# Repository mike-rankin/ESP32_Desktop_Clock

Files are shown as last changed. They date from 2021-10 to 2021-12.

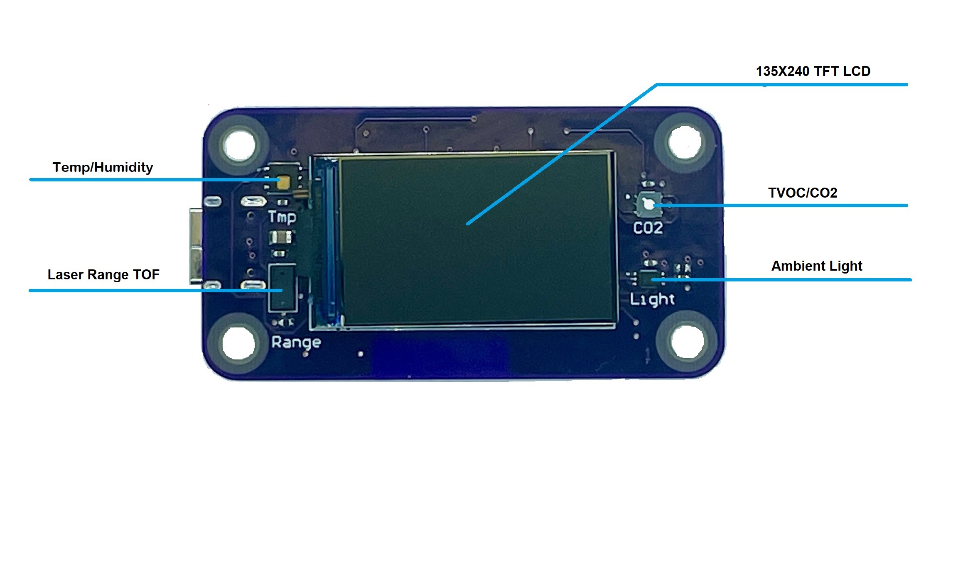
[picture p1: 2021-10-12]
Images/Front_Components.jpg

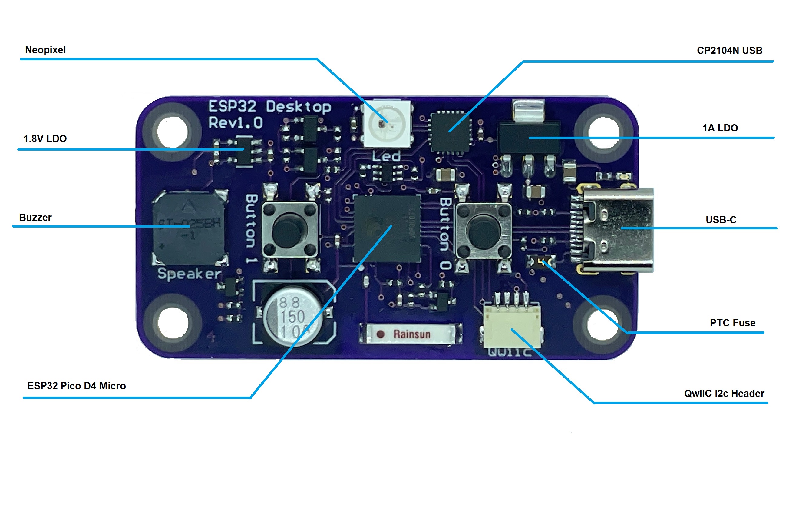
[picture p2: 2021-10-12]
Images/Back_Components.jpg

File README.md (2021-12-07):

# ESP32_Desktop_Clock
ESP32 based Desktop Clock





Front_Components

Back_Components

# Click below for a video of it doing its thing
Video of it doing its thing (https://www.youtube.com/watch?v=Y3FI6KhXrEo)

This ESP32 internet of things desktop clock is a project created for my home. School has started and fall is coming so every morning my kids ask me what they should wear. This clock is normally very, very dim and shows the time, co2 value, room temperature and humidity in a dark orange color. When you move your hand a foot or so in front, the time fades away to a screen showing the days low temperature, high and what the weather conditions will be. Time is updated every few minutes over wifi from an NTP server, local weather data is updated from Openweather with various sensors on the front. 

Hardware on this board:<br/>
-ESP32 Pico D4 processor<br/>
-temperature/humidity sensor (HDC1080DMBT)<br/>
-laser range sensor (VL53L0CXV0DH)<br/>
-CO2/TVOC (SGP-30-2.5K)<br/>
-ambient light sensor (BH1750FVI)<br/>
-135x240 TFT LCD (ER-TFT1.14-1)<br/>
-3.3V LDO (NCP1117LPST33T3G)<br/>
-1.8V LDO (RT9193-18GB)<br/>
-Neopixel LED<br/>
-USB interface (CP2104N)<br/>
-USB-C Connector<br/>
-QwiiC i2c Connector<br/>
-Buzzer<br/>

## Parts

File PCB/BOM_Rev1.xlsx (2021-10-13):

Designator | Quantity | Vendor | PartNumber | Description | Manufacturer | Value
A1 | 1 | LCSC | C99665 | Antenna Chip 2.4Gig | Rainsun | Chip Antenna
BZ1 | 1 | Digi-Key | ST-025BH | BUZZER MAGNETIC 2.7kHz Tone 2-4V SMD | SOBERTON
C1 | 1 | LCSC |  | CAP 1uF 0402 |  | 1uF
C2 | 1 | LCSC |  | CAP 22nF 0402 |  | 22nF
C3, C11 | 2 | LCSC | C83063 | CAP 1uF 16V 0402 | Walsin | 1uF
C4, C10, C14, C18 | 4 | LCSC |  | CAP 0.1uF 0402 |  | 0.1uF
C5 | 1 | LCSC | C147344 | CAP 1.5pF 0402 | Dafron | 1.5pF
C6, C8, C16, C17 | 4 | LCSC | C344190 | CAP 0.1uF 0402 | CCTC | 0.1uF
C7 | 1 | LCSC | C242018 | CAP 150uF, 10V SMT | Suncon | 150uF
C9, C15 | 2 | LCSC | C307520 | CAP 10uF 0805 | Samsung | 10uF
C12, C13 | 2 | LCSC | C162317 | CAP 10uF 16V 0805 | Murata | 10uF
D1 | 1 | LCSC | C139127 | LED,RGB,NEOPIXEL,WS2818 | Worldsemi | NeoPixel
D2 | 1 | LCSC | C74338 | LED Green 0402 |  | Green Led
F1 | 1 | LCSC |  | PTC FUSE 500mA hold, 1A trip 0805 SMD | TLC | TLC-PSMD050
H1 | 1 | Digi-Key | SM04B-SRSS-TB(LF)(SN) | CONN HEADER 4POS .100 R/A QWIIC | JST | QWiiC
J1 | 1 | LCSC | C165948 | CONN RECPT USB-C | KHE | USB-C
Q1, Q2 | 2 | LCSC | AO3400A | MOSFET N-CH 30V 35.7A SOT-23 | Alpha & Omega
Q3 | 1 | LCSC | BC847S | TRANS 2NPN 44V 0.1A SC-70-6 | Changjiang | 2NPN
Q4, Q5 | 2 | LCSC | C54879 | TRANSISTOR NPN GP 40V SC-70 | Changjiang | MMST3904
R1, R2, R3, R4 | 4 | LCSC |  | RES 4.7K 0402 |  | 4.7K
R5, R6, R7, R8, R10, R16, R19, R20, R21 | 9 | LCSC | C258091 | RES 10K 0402 | Guangdong | 10K
R9, R18 | 2 | LCSC | C106235 | RES 1K 0402 | Yageo | 1K
R11, R14 | 2 | LCSC |  | RES 5.1K 0402 |  | 5.1K
R12 | 1 | LCSC | C100310 | RES 22K 0402 | LIZ Elec | 22K
R13 | 1 | LCSC | C106232 | RES 100R 0402 | Yageo | 100R
R15 | 1 | LCSC |  | RES 1K 0402 |  | 1K
R17 | 1 | LCSC | C25092 | RES 22R 0402 | Uniroyal | 22R
S1, S2 | 2 | LCSC | C294567 | SWITCH TACTILE SPST-NO | Bright | PushButton
U1 | 1 | Digi-Key | RT9193-18GB | IC REG LDO 1.8V 300mA SOT23-5 | Richtek USA | 1.8V LDO
U2 | 1 | LCSC | C47742 | IC BRIDGE USB TO UART 24QFN | Silicon Labs | CP2104N
U3 | 1 | LCSC | C193707 | RF Transceiver ICs QFN-48_7x7x05P RoHS | Espressif | ESP32-PICO-D4
U4 | 1 | LCSC | SGP30-2.5K | TVOC/CO2 Sensor | Sensirion AG | SGP30
U5 | 1 | LCSC | C91199 | LASER SENSOR | ST MICRO | VL53L0CXV0DH/1
U6 | 1 | LCSC | C78960 | Optical Sensor Ambient I2C 6-SMD | Rohm | BH1750FVI
U7 | 1 | LCSC | NCP1117LPST33T3G | IC REG LDO 3.3V 1A SOT223-3 | ON Semi | 3.3V 1A LDO
U8 | 1 | LCSC | C82227 | Humidity/Temperature Sensor | Texas Instruments | HDC1080DMBT
X1 | 1 | BuyDisplay | ER-TFT1.14-1 | 1.14 INCH TFT GLASS COLOR | BuyDisplay | TFT_1.14"

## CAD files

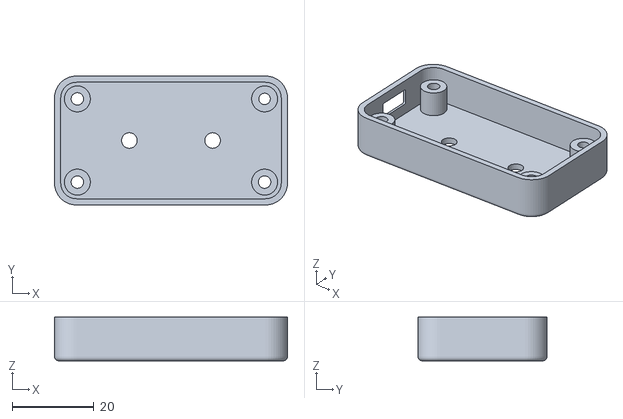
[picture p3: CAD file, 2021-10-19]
Enclosure/Bottom.stl
56.9 x 31.5 x 10.7

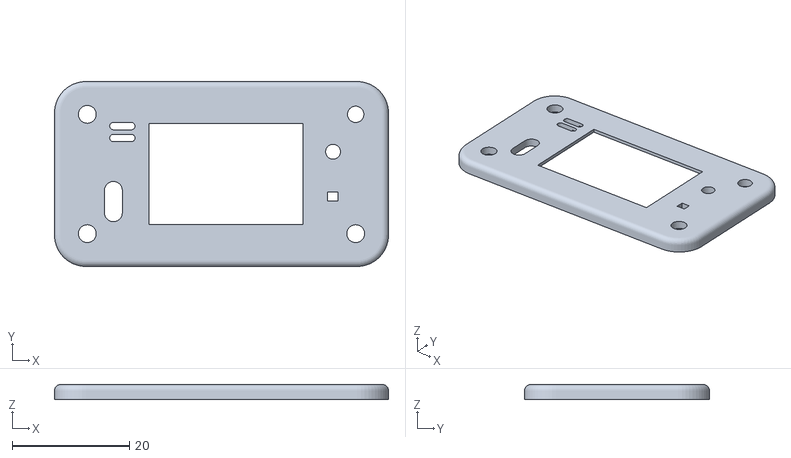
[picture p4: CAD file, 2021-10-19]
Enclosure/Top.stl
56.9 x 31.5 x 2.54

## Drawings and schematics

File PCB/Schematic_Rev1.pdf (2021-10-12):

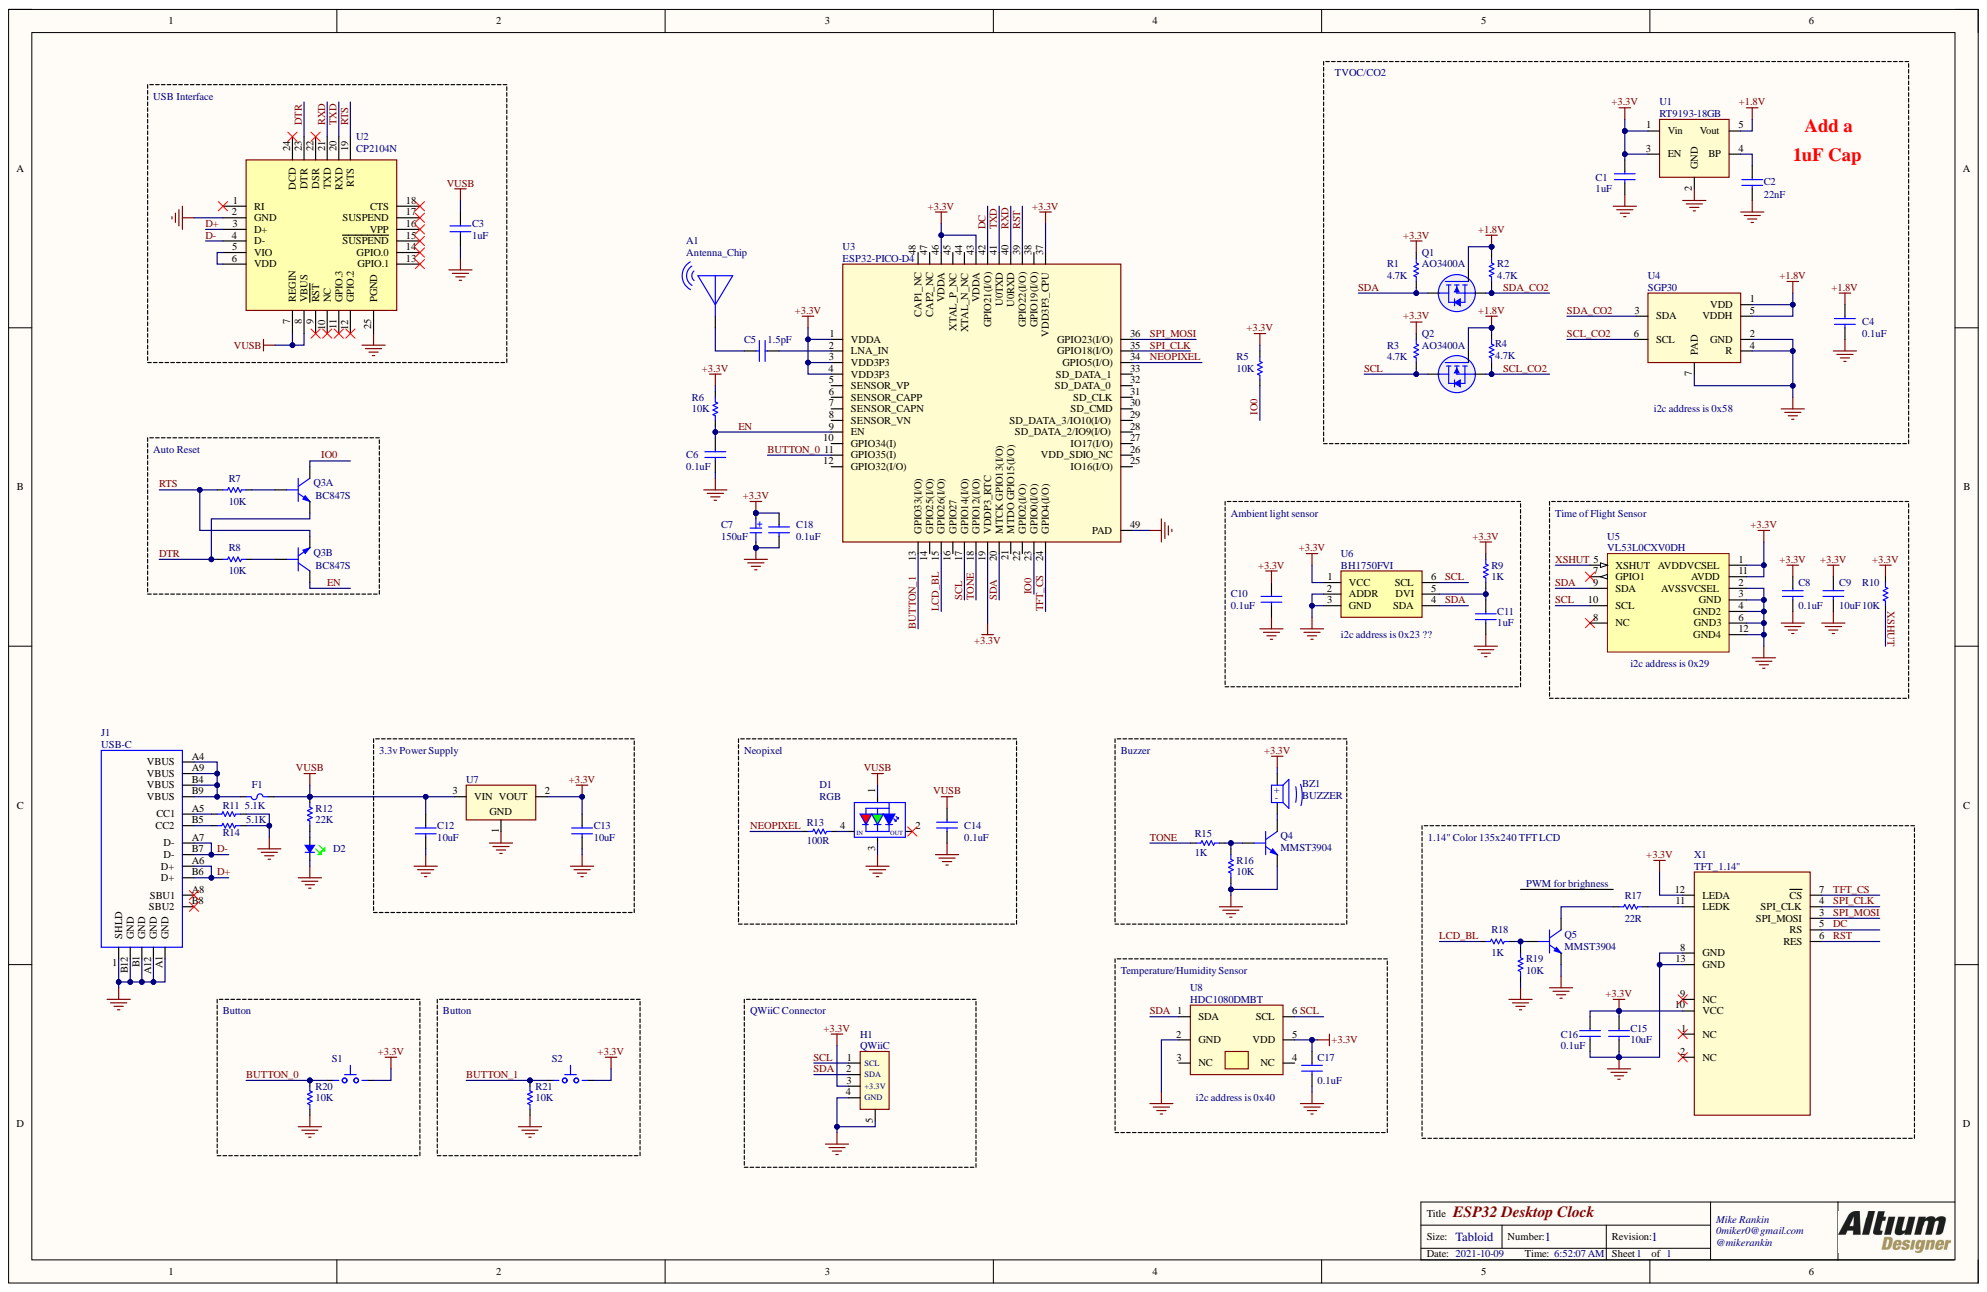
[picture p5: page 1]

RTS 19 RXD 20 TXD 21 DSR 22 DTR 23

A9 4 VBUS

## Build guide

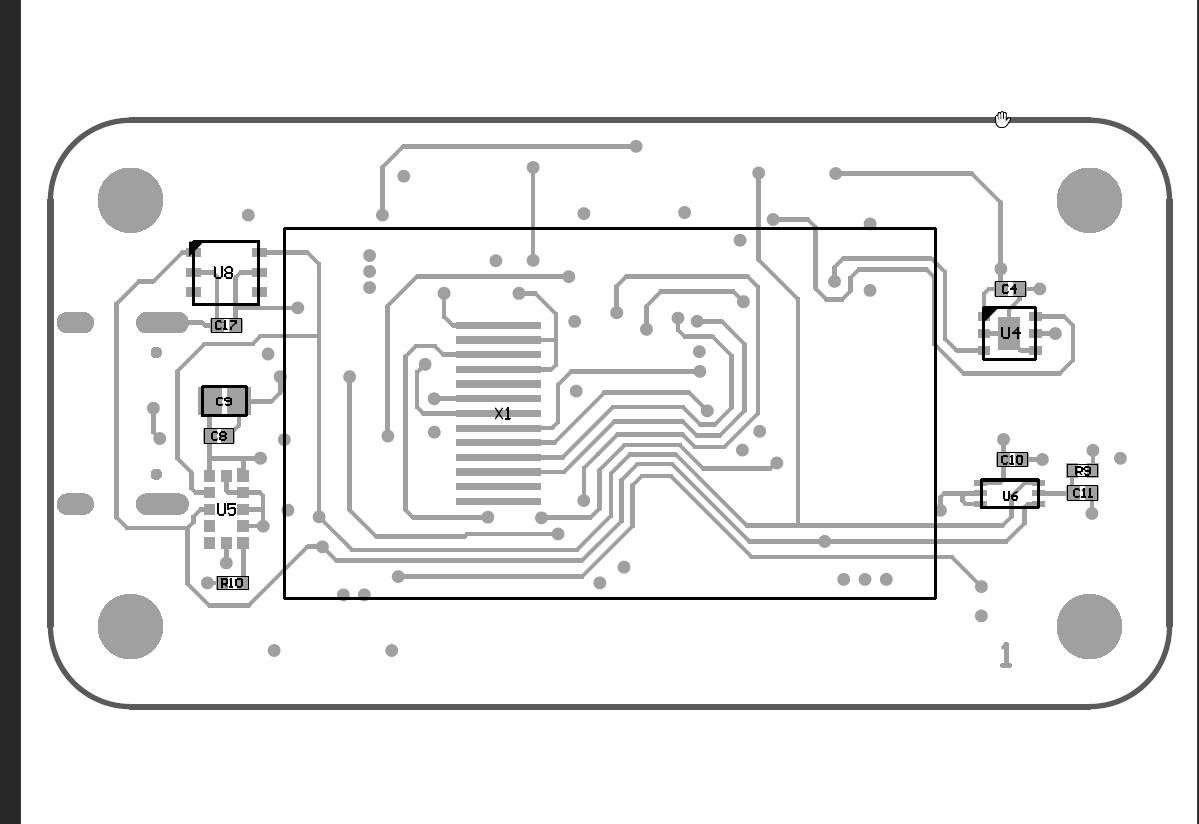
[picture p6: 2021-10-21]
PCB/Top_Assembly.jpg

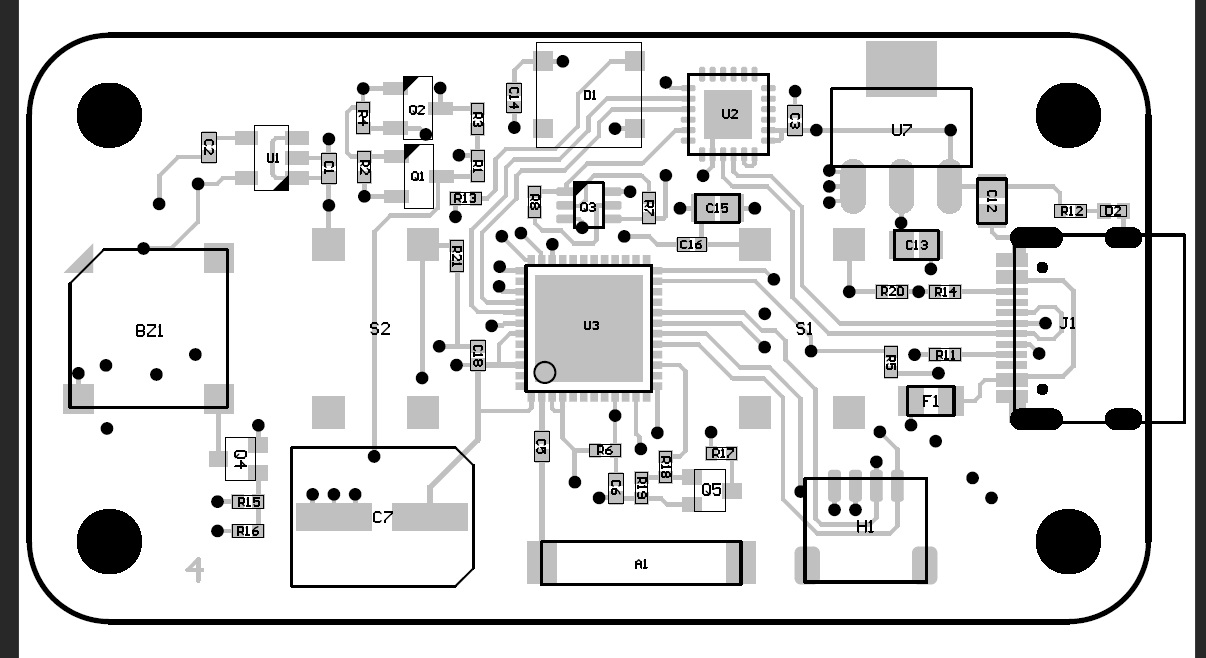
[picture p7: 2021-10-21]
PCB/Bottom_Assembly.jpg

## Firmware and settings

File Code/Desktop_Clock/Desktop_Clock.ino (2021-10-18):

//This project was based off of Volos Projects: https://www.youtube.com/channel/UCit2rVgOvhyuAD-VH5H_IHg
//and
//That Project: https://www.youtube.com/channel/UCRr2LnXXXuHn4z0rBvpfG7w
//Huge thank you to these guys!

//The display library files have to be modified and are added along with this sketch

#include <Wire.h>
#include <BH1750.h>
#include <Adafruit_NeoPixel.h>
#include "Adafruit_SGP30.h"
#include "ClosedCube_HDC1080.h"
#include "Adafruit_VL53L0X.h"
#include "icons.h"
#include <TJpg_Decoder.h>  //The jpeg decoder library
#include <TFT_eSPI.h> // Graphics and font library for ST7735 driver chip
#include <SPI.h>
#include <ArduinoJson.h>         //https://github.com/bblanchon/ArduinoJson.git
#include <NTPClient.h>           //https://github.com/taranais/NTPClient
#include <WiFi.h>
#include <WiFiUdp.h>
#include <HTTPClient.h>
#include <ArduinoJson.h>         //https://github.com/bblanchon/ArduinoJson.git

#define TFT_BACKLIGHT  26

BH1750 lightMeter;
TFT_eSPI tft = TFT_eSPI();  // Invoke library, pins defined in User_Setup.h
Adafruit_VL53L0X lox = Adafruit_VL53L0X();
ClosedCube_HDC1080 hdc1080;
Adafruit_SGP30 sgp;
Adafruit_NeoPixel pixels(1, 5, NEO_GRB + NEO_KHZ800);

#include "Orbitron_Medium_20.h"
#define TFT_GREY 0x5AEB
#define TFT_lightblue 0x01E9
#define TFT_darkred 0xA041
#define TFT_blue 0x5D9B
#define TFT_aqua 0x04FF
#define TFT_yellow 0xFFE0
#define TFT_olive 0x7BE0
#define TFT_purple 0x780F
#define TFT_maroon 0x7800
#define TFT_navy 0x000F
#define TFT_silver 0xA510
#define TFT_brown 0x8200
#define TFT_violet 0x9199
#define TFT_red 0xF800
#define TFT_lime 0x87E0
#define TFT_light_grey 0xC618

//Buzzer
const int ledPin = 12;  //Buzzer
const int buzzer_freq = 5000;
const int buzzer_ledChannel = 1;
const int buzzer_resolution = 8;

byte omm = 99;
bool initial = 1;
byte xcolon = 0;
unsigned int colour = 0;

//Poll Weather interval
const long interval = 60000; 
unsigned long previousMillis = 0;    //will store last time weather conditions were updated    

//PWM properties
const int freq = 5000;
const int ledChannel = 0;
const int resolution = 8; 

uint32_t targetTime = 0;       // for next 1 second timeout

//CO2
uint32_t getAbsoluteHumidity(float temperature, float humidity)
{
 // approximation formula from Sensirion SGP30 Driver Integration chapter 3.15
 const float absoluteHumidity = 216.7f * ((humidity / 100.0f) * 6.112f * exp((17.62f * temperature) / (243.12f + temperature)) / (273.15f + temperature)); // [g/m^3]
 const uint32_t absoluteHumidityScaled = static_cast<uint32_t>(1000.0f * absoluteHumidity); // [mg/m^3]
 return absoluteHumidityScaled;
}

//Replace with your network credentials
const char *ssid     = "SSID";        
const char *password = "PASSWORD";  

//Open Weather Settings
String town="Hantsport";            //EDDIT
String Country="CA";                //EDDIT
const String endpoint = "http://api.openweathermap.org/data/2.5/weather?q="+town+","+Country+"&units=metric&APPID=";
const String key = "API KEY"; /*Open Weather API Key*/
String formattedDate;
String dayStamp;

String payload=""; //whole json 
String tmp="" ; //temperature
String hum="" ; //humidity
String weather="" ; //weather
String description="" ; //description
String tempmin="" ; //temperature
String tempmax="" ; //temperature
int weatherID = 0;  
int id;  

StaticJsonDocument<1000> doc;

//Define NTP Client to get time
WiFiUDP ntpUDP;
NTPClient timeClient(ntpUDP, "pool.ntp.org");

bool tft_output(int16_t x, int16_t y, uint16_t w, uint16_t h, uint16_t* bitmap)
{
  if ( y >= tft.height() ) return 0; //Stop further decoding as image is running off bottom of screen
  tft.pushImage(x, y, w, h, bitmap);  //clips the image block rendering automatically at the TFT boundaries
  return 1;    //Return 1 to decode next block
}

void Dim_Display()
{
 ledcWrite(ledChannel, 20);  //DIM 
 for(int dutyCycle = 255; dutyCycle >= 10; dutyCycle--)
 {
  ledcWrite(ledChannel, dutyCycle);  //decrease the LED brightness
  delay(15);
 }
} 

void Brighten_Display()
{
 for(int dutyCycle = 10; dutyCycle <= 255; dutyCycle++)
 {   
  ledcWrite(ledChannel, dutyCycle); //increase the LED brightness
  delay(15);
 }
} 

void setup() 
{
 Serial.begin(115200);
 Wire.begin(13,14);
 delay(150);
  
 ledcSetup(ledChannel, buzzer_freq, resolution);  //PWM
 ledcAttachPin(ledPin, buzzer_ledChannel);        //GPIO Pin
 ledcWriteTone(buzzer_ledChannel, 500);           //Freq
 beep_beep();
  
 lightMeter.begin();
  
 pixels.setBrightness(150); // Set BRIGHTNESS to about 1/5 (max = 255)
 pixels.begin();
 
 tft.init();
 tft.setRotation(3);
 tft.fillScreen(TFT_BLACK);
 tft.setTextColor(TFT_GREEN, TFT_BLACK);

 TJpgDec.setJpgScale(2);  //The jpeg image can be scaled by a factor of 1, 2, 4, or 8
 TJpgDec.setSwapBytes(true);  //The byte order can be swapped (set true for TFT_eSPI)
 TJpgDec.setCallback(tft_output);  //The decoder must be given the exact name of the rendering function above

 hdc1080.begin(0x40);

 pinMode(TFT_BACKLIGHT, OUTPUT);

 //PWM Stuff
 ledcSetup(ledChannel, freq, resolution);    // configure LED PWM functionalitites
 ledcAttachPin(TFT_BACKLIGHT , ledChannel);  // attach the channel to the GPIO to be controlled 

 Brighten_Display();
  
 Serial.println("Adafruit VL53L0X test");
 if (!lox.begin()) 
 {
  Serial.println(F("Failed to boot VL53L0X"));
  while(1);
 }

 if (! sgp.begin())
 {
  Serial.println("Sensor not found :(");
  while (1);
 }
 Serial.print("Found SGP30 serial #");
 Serial.print(sgp.serialnumber[0], HEX);
 Serial.print(sgp.serialnumber[1], HEX);
 Serial.println(sgp.serialnumber[2], HEX);

 // Connect to Wi-Fi
 Serial.print("Connecting to ");
 tft.println("Connecting to Wifi");
 Serial.println(ssid);
 WiFi.begin(ssid, password);
 while (WiFi.status() != WL_CONNECTED) 
 {
  delay(500);
  Serial.print(".");
  tft.print(".");
 }

 tft.println("");
 tft.println("WiFi connected.");
 tft.println("IP address: ");
 tft.println(WiFi.localIP());
 delay(3000);
 
 //Initialize a NTPClient to get time
 timeClient.begin();
 timeClient.setTimeOffset(-10800);  //My timezone

 targetTime = millis() + 1000; 
 delay(500);
 tft.fillScreen(TFT_BLACK);
 timeClient.update();
} 

int counter = 0; int temp; int red; int green;
void loop() 
{
  VL53L0X_RangingMeasurementData_t measure;
  static int iOldDistance, iDistance;
  int iChanged = 0;
  if (! sgp.IAQmeasure()) 
  {
   Serial.println("Measurement failed");
   return;
  }

  if (! sgp.IAQmeasureRaw()) 
  {
   Serial.println("Raw Measurement failed");
   return;
  }
  
  pixels.clear();
  Serial.println(sgp.eCO2);
  temp = sgp.eCO2;
  temp = constrain(temp, 400, 1500);
  Serial.println(temp);
  red = map(temp, 400, 1500, 0, 250);
  green = 250 - red; // since the range is 0 to 250
  Serial.print("Mapped: ");
  Serial.println(red);

  pixels.setPixelColor(0, pixels.Color(red, green, 0));
  pixels.show(); 

  //LightMeter
  float lux = lightMeter.readLightLevel();
  Serial.print("Light: ");
  Serial.print(lux);
  Serial.println(" lx"); 
  
  measure_CO2();
   
  unsigned long currentMillis = millis(); 
  ledcWrite(ledChannel, 20); //Display brightness dim
   
  if (currentMillis - previousMillis >= interval) 
  {
   previousMillis = currentMillis; 
   timeClient.update();
   Serial.println("Time Updated");
   Serial.print("eCO2 "); Serial.println(sgp.eCO2); 
   Serial.println("CO2 Level");
  }
       
  Serial.print("Reading a Range Distance");
  lox.rangingTest(&measure, false); // pass in 'true' to get debug data printout!
 
  if (measure.RangeStatus != 4) 
  {
   Serial.print("Distance (mm): "); Serial.println(iDistance);
  } 
  else 
  {
   Serial.println(" out of range ");
  } 
 
  Serial.print("Distance (mm): "); Serial.println(iDistance);
  unsigned long epochTime = timeClient.getEpochTime();
  Serial.print("Epoch Time: ");
  Serial.println(epochTime);
  
  String formattedTime = timeClient.getFormattedTime();
  Serial.print("Formatted Time: ");
  Serial.println(formattedTime);  

  int currentHour = timeClient.getHours();
  Serial.print("Hour: ");
  Serial.println(currentHour);  

  int currentMinute = timeClient.getMinutes();
  Serial.print("Minutes: ");
  Serial.println(currentMinute); 
   
  int currentSecond = timeClient.getSeconds();
  Serial.print("Seconds: ");
  Serial.println(currentSecond);  
  
  iDistance = (int)measure.RangeMilliMeter;

  if ((iDistance > 25) && (iDistance < 400))// Hand over sensor
  { 
   getData();  //Could be too slow
   formattedDate = timeClient.getFormattedTime();
   int splitT = formattedDate.indexOf("T");
   dayStamp = formattedDate.substring(0, splitT); 
   tft.fillScreen(TFT_BLACK);
   tft.drawLine( 0, 0, 240, 0, TFT_WHITE);   //Line top across
   tft.drawLine( 0, 0, 0, 135,TFT_WHITE);    //Line top down
   tft.drawLine( 0, 134, 240, 134, TFT_WHITE);  //Line bottom across
   tft.drawLine( 239, 0, 239, 134, TFT_WHITE);  //Line at end, down
   tft.drawLine( 0, 63, 148, 63, TFT_WHITE);    //Line at middle across
   tft.drawLine( 148, 0, 148, 148,TFT_WHITE);  //Aqua=0x04FF, Yellow = 0xFFE0,80, 0, 80, 80
   tft.setCursor(7, 20);  //over, down
   tft.setFreeFont(&Orbitron_Medium_20);
   tft.setTextColor(TFT_WHITE,TFT_BLACK);
   tft.setTextSize(1);
   tft.print("Low Temp: ");
   tft.setFreeFont(&Orbitron_Medium_20);
   tft.setCursor(35, 45);
   tft.setTextColor(TFT_aqua,TFT_BLACK);
   tft.print(tempmin); 
   tft.print(" `");  
   tft.print("C");

   tft.setCursor(7, 90);  //over, down
   tft.setTextColor(TFT_WHITE,TFT_BLACK);
   tft.setTextSize(1);
   tft.print("High Temp: ");
   tft.setFreeFont(&Orbitron_Medium_20);
   tft.setCursor(35, 120);
   tft.setTextColor(TFT_darkred,TFT_BLACK);
   tft.print(tempmax);
   tft.print(" `");  
   tft.print("C");

   if(id == 501)
   {
    TJpgDec.drawJpg(160, 25, rain, sizeof(rain));   //// Draw the image, over and down, 100, 20
   }

   if(id == 800)
   {
    TJpgDec.drawJpg(160, 25, sun, sizeof(sun));   //// Draw the image, over and down
   }

   if(id == 801 || id == 802 || id == 803 || id == 804)
   {
    TJpgDec.drawJpg(155, 25, cloudy, sizeof(cloudy));   //// Draw the image, over and down
   }

   else
   { 
   }

   //233=storm, 499=showers, 501=rain, 599=snow, 699=fog, 802=cloud, 804-cloud
   
   //Draw weather Index number
   tft.setCursor(175, 18);  //over, down
   tft.setTextColor(TFT_WHITE,TFT_BLACK);
   tft.setTextSize(1);
   tft.print(id);
   
   Brighten_Display();
     
   delay(5000);
   Dim_Display();
   tft.fillScreen(TFT_BLACK);  
  } 
 
  else 
  {
   ledcWrite(ledChannel, 20); //Keep dim
  }

  byte xpos = 40; //10 over
  byte ypos = 45; //15 down
    
  if (omm != currentMinute) 
  { 
   tft.setTextColor(0x39C4, TFT_BLACK);  // Leave a 7 segment ghost image, comment out next line!
   tft.drawString("88:88",xpos,ypos,7); // Overwrite the text to clear it
   tft.setTextColor(0xF9C0); // Orange
   omm = currentMinute;

   if (currentHour > 12) currentHour -= 12;
   else if (currentHour == 0) currentHour += 12;
     
   if (currentHour < 10)
   {
    xpos+= 32; 
   }
            
   xpos+= tft.drawNumber(currentHour,xpos,ypos,7); 
   xcolon=xpos;
   xpos+= tft.drawChar(':',xpos,ypos,7);
      
   if (currentMinute<10) xpos+= tft.drawChar('0',xpos,ypos,7);
   tft.drawNumber(currentMinute,xpos,ypos,7);
  }

  if (currentSecond%2) // Flash the colon
  { 
   tft.setTextColor(0x39C4, TFT_BLACK);
   xpos+= tft.drawChar(':',xcolon,45,7);  
   tft.setTextColor(0xFBE0, TFT_BLACK);
  }

  else 
  {
   tft.drawChar(':',xcolon,45,7);
   tft.setTextColor(0xF9C0, TFT_BLACK);
  }
} 

void getData()
{
 tft.fillRect(1,170,64,20,TFT_BLACK);
 tft.fillRect(1,210,64,20,TFT_BLACK);
 if ((WiFi.status() == WL_CONNECTED))
 { 
  HTTPClient http;
  http.begin(endpoint + key); //Specify the URL
  int httpCode = http.GET();  //Make the request
 
  if (httpCode > 0)
  { 
   payload = http.getString();
   Serial.println(payload);   
  }

  else 
  {
   Serial.println("Error on HTTP request");
  }
 
  http.end(); 
 }
  char inp[1000];
  payload.toCharArray(inp,1000);
  deserializeJson(doc,inp);
 
  id = doc["weather"][0]["id"];
  String description = doc["weather"][0]["description"];
    
  String tmp2 = doc["main"]["temp"];
  String hum2 = doc["main"]["humidity"];
  String tempmin2 = doc["main"]["temp_min"];
  String tempmax2 = doc["main"]["temp_max"];

  tmp=tmp2;
  hum=hum2;
  tempmin=tempmin2;
  tempmax=tempmax2;
  
  Serial.println(id); 
  Serial.println(description);  //Weather Description
  Serial.println("Temp: "+String(tmp));
  Serial.println("Humidity: "+hum);
  Serial.println("Temp Min: "+tempmin);
  Serial.println("Temp Max: "+tempmax); 
}
         
void measure_CO2()
{ 
 if (! sgp.IAQmeasure()) 
  {
   Serial.println("Measurement failed");
   return;
  }
  Serial.print("eCO2 ");
  Serial.print(sgp.eCO2);
  Serial.println(" ppm");
  tft.setTextColor(0xF9C0, TFT_BLACK);
  char temp_out[] = " ";
  float temperature_sensor = hdc1080.readTemperature();
  dtostrf(temperature_sensor,4,1,temp_out);
  tft.drawString(temp_out, 0, 0, 4);
  tft.drawString("'C", 55, 0, 4);

  char humidity_out[] = " ";
  float humidity_sensor = hdc1080.readHumidity();
  dtostrf(humidity_sensor,4,1,humidity_out);
  tft.drawString(humidity_out, 135, 0, 4);
  tft.drawString("%H", 195, 0, 4);

  tft.setTextColor(0xF9C0, TFT_BLACK);
  tft.drawString("C02: ", 0, 115, 4);
  char co2_buf[8]; dtostrf(sgp.eCO2, 4, 0, co2_buf);    //Super Fast Refresh!
  tft.drawString(co2_buf, 50, 115, 4);
  Serial.println("CO2 Measured !!!!!!!!");

  tft.setTextColor(0xF9C0, TFT_BLACK);
  tft.drawString("TVOC: ", 122, 115, 4);
  char tvoc_buf[8]; dtostrf(sgp.TVOC, 4, 0, tvoc_buf);    //Super Fast Refresh!
  tft.drawString(co2_buf, 185, 115, 4);
  Serial.println("TVOC Measured !!!!!!!!");

  if (! sgp.IAQmeasureRaw()) 
  {
   Serial.println("Raw Measurement failed");
   return;
  }
 
  counter++;
  if (counter == 30) 
  {
   counter = 0;
   uint16_t TVOC_base, eCO2_base;
   if (! sgp.getIAQBaseline(&eCO2_base, &TVOC_base)) 
   {
    Serial.println("Failed to get baseline readings");
    return;
    }
    Serial.print("****Baseline values: eCO2: 0x"); Serial.print(eCO2_base, HEX);
    Serial.print(" & TVOC: 0x"); Serial.println(TVOC_base, HEX);
  }
}


void beep_beep() 
{
 //ledcWriteTone(buzzer_ledChannel, 500);                         
 //delay(50);  
 //ledcWriteTone(buzzer_ledChannel, 0);                       
 //delay(50); 
 //ledcWriteTone(buzzer_ledChannel, 500);                       
 //delay(50);  
 ledcWriteTone(buzzer_ledChannel, 0);                                               
}

     

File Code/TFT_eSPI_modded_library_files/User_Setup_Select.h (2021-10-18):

// This header file contains a list of user setup files and defines which one the
// compiler uses when the IDE performs a Verify/Compile or Upload.
//
// Users can create configurations for different Espressif boards and TFT displays.
// This makes selecting between hardware setups easy by "uncommenting" one line.

// The advantage of this hardware configuration method is that the examples provided
// with the library should work with different setups immediately without any other
// changes being needed. It also improves the portability of users sketches to other
// hardware configurations and compatible libraries.
//
// Create a shortcut to this file on your desktop to permit quick access for editing.
// Re-compile and upload after making and saving any changes to this file.

// Customised User_Setup files are stored in the "User_Setups" folder.

#ifndef USER_SETUP_LOADED //  Lets PlatformIO users define settings in
                          //  platformio.ini, see notes in "Tools" folder.

// Only ONE line below should be uncommented.  Add extra lines and files as needed.

//#include <User_Setup.h>           // Default setup is root library folder

//#include <User_Setups/Setup1_ILI9341.h>  // Setup file configured for my ILI9341
//#include <User_Setups/Setup2_ST7735.h>   // Setup file configured for my ST7735
//#include <User_Setups/Setup3_ILI9163.h>  // Setup file configured for my ILI9163
//#include <User_Setups/Setup4_S6D02A1.h>  // Setup file configured for my S6D02A1
//#include <User_Setups/Setup5_RPi_ILI9486.h>        // Setup file configured for my stock RPi TFT
//#include <User_Setups/Setup6_RPi_Wr_ILI9486.h>     // Setup file configured for my modified RPi TFT
//#include <User_Setups/Setup7_ST7735_128x128.h>     // Setup file configured for my ST7735 128x128 display
//#include <User_Setups/Setup8_ILI9163_128x128.h>    // Setup file configured for my ILI9163 128x128 display
//#include <User_Setups/Setup9_ST7735_Overlap.h>     // Setup file configured for my ST7735
//#include <User_Setups/Setup10_RPi_touch_ILI9486.h> // Setup file configured for ESP8266 and RPi TFT with touch

//#include <User_Setups/Setup11_RPi_touch_ILI9486.h> // Setup file configured for ESP32 and RPi TFT with touch
//#include <User_Setups/Setup12_M5Stack.h>           // Setup file for the ESP32 based M5Stack
//#include <User_Setups/Setup13_ILI9481_Parallel.h>  // Setup file for the ESP32 with parallel bus TFT
//#include <User_Setups/Setup14_ILI9341_Parallel.h>  // Setup file for the ESP32 with parallel bus TFT
//#include <User_Setups/Setup15_HX8357D.h>           // Setup file configured for HX8357D (untested)
//#include <User_Setups/Setup16_ILI9488_Parallel.h>  // Setup file for the ESP32 with parallel bus TFT
//#include <User_Setups/Setup17_ePaper.h>            // Setup file for any Waveshare ePaper display
//#include <User_Setups/Setup18_ST7789.h>            // Setup file configured for ST7789

//#include <User_Setups/Setup19_RM68140_Parallel.h>	 // Setup file configured for RM68140 with parallel bus

//#include <User_Setups/Setup20_ILI9488.h>           // Setup file for ESP8266 and ILI9488 SPI bus TFT
//#include <User_Setups/Setup21_ILI9488.h>           // Setup file for ESP32 and ILI9488 SPI bus TFT

//#include <User_Setups/Setup22_TTGO_T4.h>           // Setup file for ESP32 and TTGO T4 version 1.2
//#include <User_Setups/Setup22_TTGO_T4_v1.3.h>      // Setup file for ESP32 and TTGO T4 version 1.3
//#include <User_Setups/Setup23_TTGO_TM.h>           // Setup file for ESP32 and TTGO TM ST7789 SPI bus TFT
//#include <User_Setups/Setup24_ST7789.h>            // Setup file configured for ST7789 240 x 240
//#include <User_Setups/Setup25_TTGO_T_Display.h>    // Setup file for ESP32 and TTGO T-Display ST7789V SPI bus TFT
//#include <User_Setups/Setup26_TTGO_T_Wristband.h>  // Setup file for ESP32 and TTGO T-Wristband ST7735 SPI bus TFT

//#include <User_Setups/Setup27_RPi_ST7796_ESP32.h>    // ESP32   RPi MHS-4.0 inch Display-B
//#include <User_Setups/Setup28_RPi_ST7796_ESP8266.h>  // ESP8266 RPi MHS-4.0 inch Display-B

//#include <User_Setups/Setup29_ILI9341_STM32.h>          // Setup for Nucleo board
//#include <User_Setups/Setup30_ILI9341_Parallel_STM32.h> // Setup for Nucleo board and parallel display
//#include <User_Setups/Setup31_ST7796_Parallel_STM32.h>  // Setup for Nucleo board and parallel display
//#include <User_Setups/Setup32_ILI9341_STM32F103.h>      // Setup for "Blue/Black Pill"

//#include <User_Setups/Setup33_RPi_ILI9486_STM32.h>      // Setup for Nucleo board

//#include <User_Setups/Setup34_ILI9481_Parallel_STM32.h> // Setup for Nucleo board and parallel display
//#include <User_Setups/Setup35_ILI9341_STM32_Port_Bus.h> // Setup for STM32 port A parallel display

//#include <User_Setups/Setup36_RPi_touch_ST7796.h>      // Setup file configured for ESP32 and RPi ST7796 TFT with touch

//#include <User_Setups/Setup43_ST7735.h>            // Setup file configured for my ST7735S 80x160
//#include <User_Setups/Setup44_TTGO_CameraPlus.h>   // Setup file for ESP32 and TTGO T-CameraPlus ST7789 SPI bus TFT    240x240
//#include <User_Setups/Setup45_TTGO_T_Watch.h>      // Setup file for ESP32 and TTGO T-Watch ST7789 SPI bus TFT  240x240

//#include <User_Setups/Setup47_ST7735.h>            // Setup file configured for ST7735 128 x 128 animated eyes

//#include <User_Setups/Setup50_SSD1963_Parallel.h>  // Setup file for ESP32 and SSD1963 TFT display

//#include <User_Setups/Setup51_LilyPi_ILI9481.h>    // Setup file for LilyGo LilyPi with ILI9481 display

//#include <User_Setups/Setup60_RP2040_ILI9341.h>    // Setup file for Raspberry Pi Pico with SPI ILI9341

#include <User_Setups/Setup135_ST7789.h>           // Setup file for ESP8266 and ST7789 135 x 240 TFT

//#include <User_Setups/Setup136_LilyGo_TTV.h>       // Setup file for ESP32 and Lilygo TTV ST7789 SPI bus TFT  135x240

//#include <User_Setups/Setup200_GC9A01.h>           // Setup file for ESP32 and GC9A01 240 x 240 TFT

//#include <User_Setups/Setup201_WT32_SC01.h>        // Setup file for ESP32 based WT32_SC01 from Seeed

//#include <User_Setups/Setup202_SSD1351_128.h>      // Setup file for ESP32/ESP8266 based SSD1351 128x128 1.5inch OLED display

//#include <User_Setups/SetupX_Template.h>


#endif // USER_SETUP_LOADED



/////////////////////////////////////////////////////////////////////////////////////
//                                                                                 //
//     DON'T TINKER WITH ANY OF THE FOLLOWING LINES, THESE ADD THE TFT DRIVERS     //
//       AND ESP8266 PIN DEFINITONS, THEY ARE HERE FOR BODMER'S CONVENIENCE!       //
//                                                                                 //
/////////////////////////////////////////////////////////////////////////////////////
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

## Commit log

2021-10-13 Added BOM
    [BOM_Rev1.xlsx]
2021-10-18 Added top assembly
2021-10-19 Added enclosure
    [Bottom.stl, Top.stl]
2021-10-19 Added images
    [Bottom.stl, Top.stl]
2021-10-21 Added assembly maps
